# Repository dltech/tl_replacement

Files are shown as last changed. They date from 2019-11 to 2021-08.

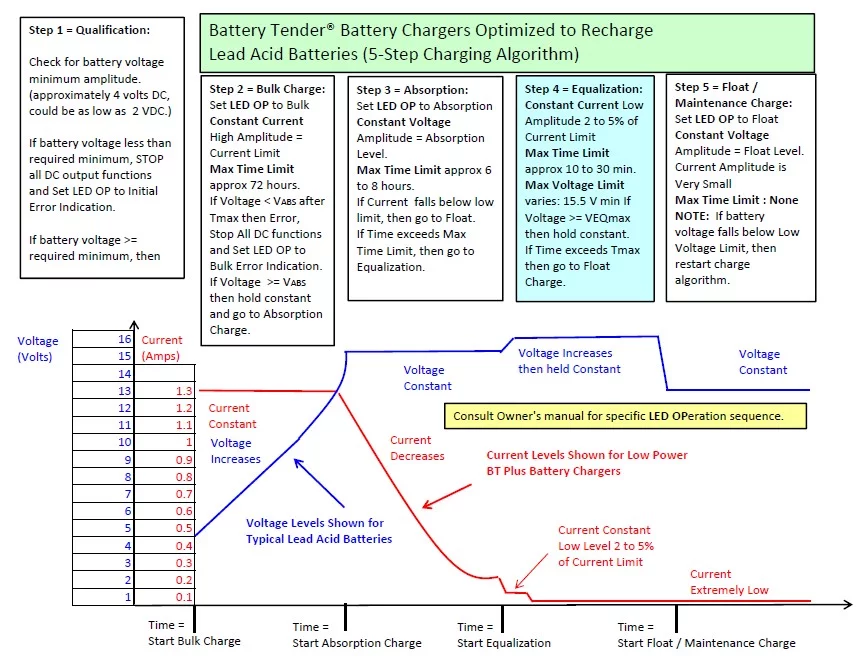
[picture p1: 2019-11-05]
sch_doc/datasheets/Lead_Acid_5_Step_Charging.webp

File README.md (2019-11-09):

A replacement for a driver in old ATX power suplies. May be conected direcly to
the coils of isolaton transformer. Powered by Vsb and controls only one channel
by current and volage. Includes submodule with display and simple menu. 
Functions:

Short circuit protection (checks every 0.1ms).

Current and voltage stabilization.

Mode for control charging 12V and 6V lead acid batteries.

Fan speed control.

It is based on libopencm3 libraries
# Instructions
 1. git clone https://github.com/libopencm3/libopencm3-template.git zarjadnik
 2. cd zarjadnik
 3. git submodule update --init # (Only needed once)
 4. make -C libopencm3 # (Only needed once)
 5. make -C zarjadnik

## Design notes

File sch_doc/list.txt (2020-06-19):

STM32F030F4P6	x1
78HC595		x2
AP1117-33	x1
0.1 мкФ		х8
10 нФ		х4
100 Ом		х3
200 Ом		х3
510 Ом		х1
1 кОм		х2
1.5 кОм		х1
4.7 кОм		х1
63 Ом 1210	х1
0.1 Ом 1210	х10
тактовая кнопка	х2
7 сегментник 	х1
потенциометр	х1
PLS		x5
винтовой разъем х2
BAW156		x1
BAV70		x1
BZX84-C5V1	x2
PESD1CAN	x1
47 мкГн 1210	х1
BCR158		x1
BCR108		x2

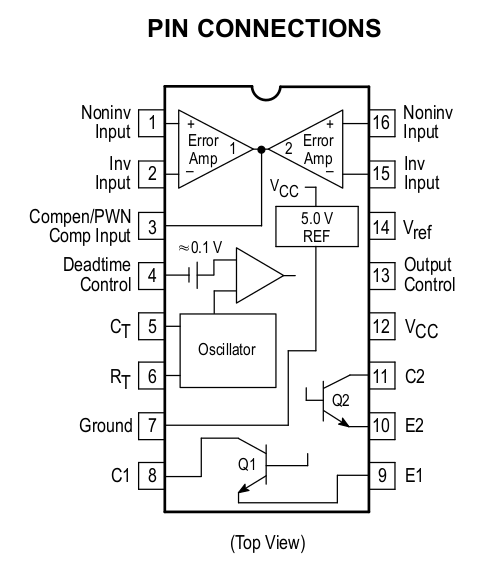
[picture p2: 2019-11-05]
sch_doc/datasheets/PWM diver/TL_PINOUT.png

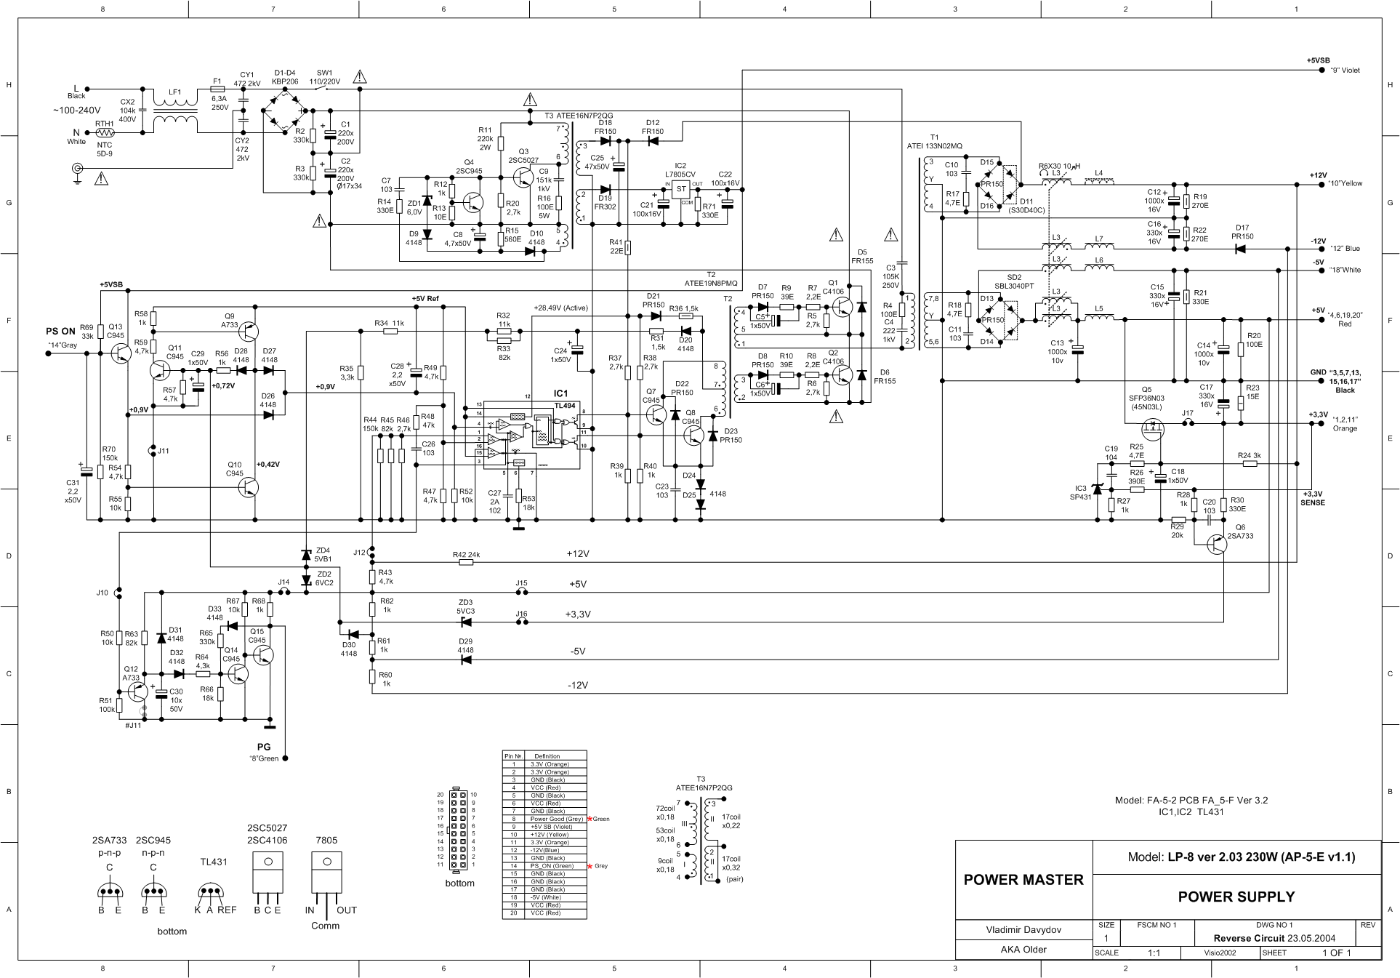
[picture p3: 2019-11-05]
sch_doc/datasheets/ATX/PowerMaster_LP-8-v.gif

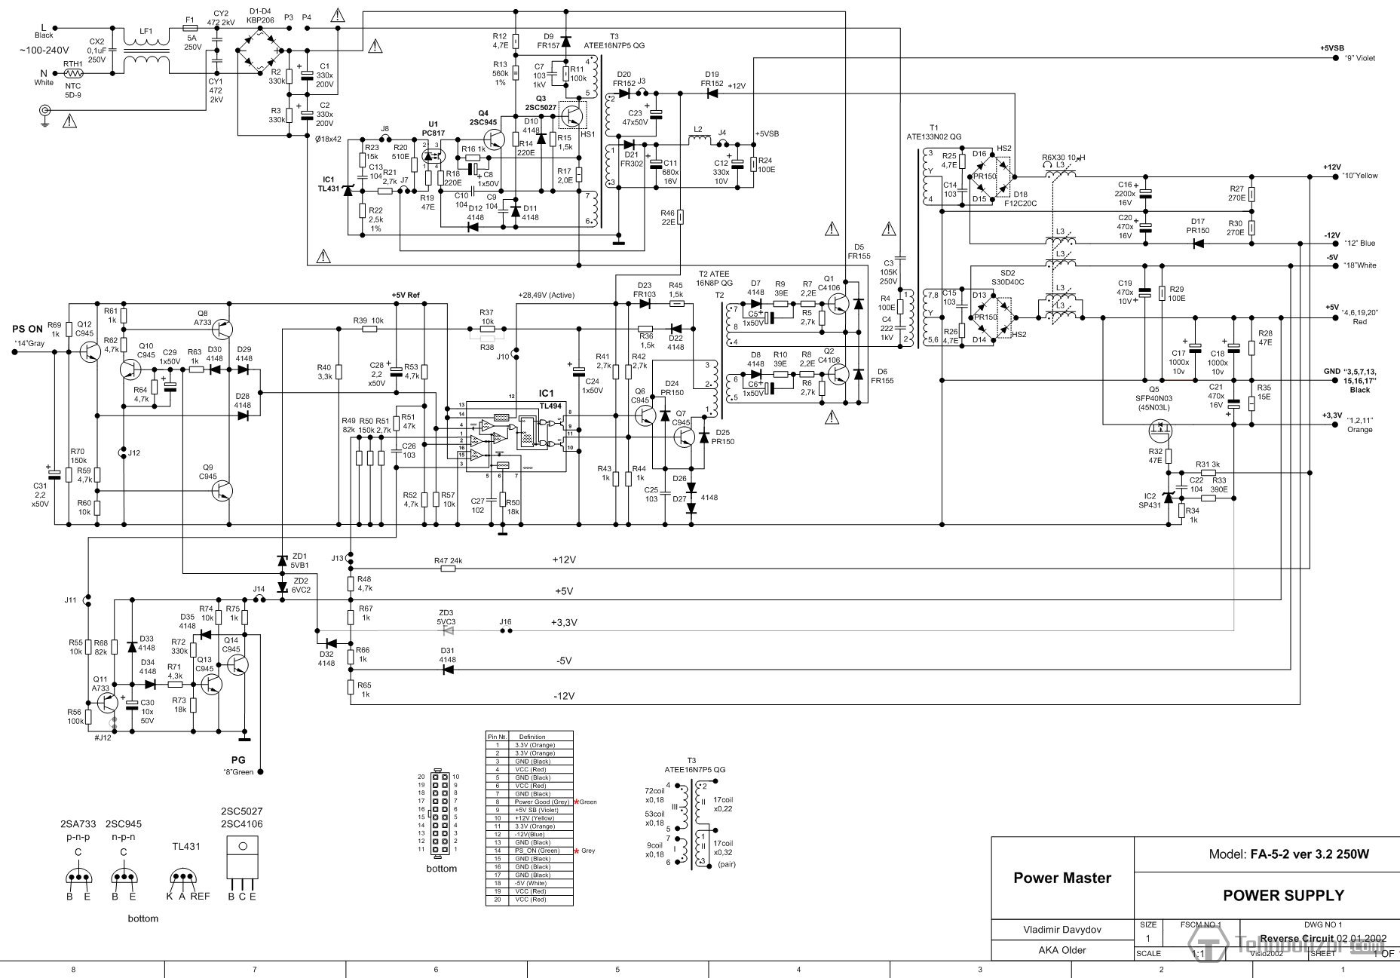
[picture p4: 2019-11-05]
sch_doc/datasheets/ATX/1368205779_shema-atx.jpg

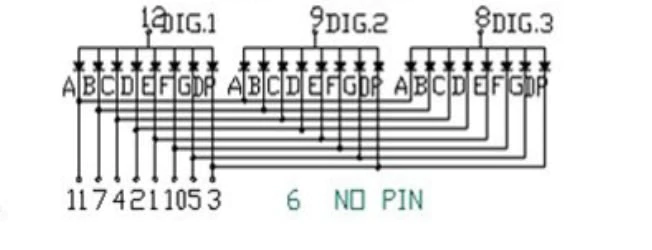
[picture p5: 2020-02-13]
sch_doc/datasheets/3 digits ali.webp

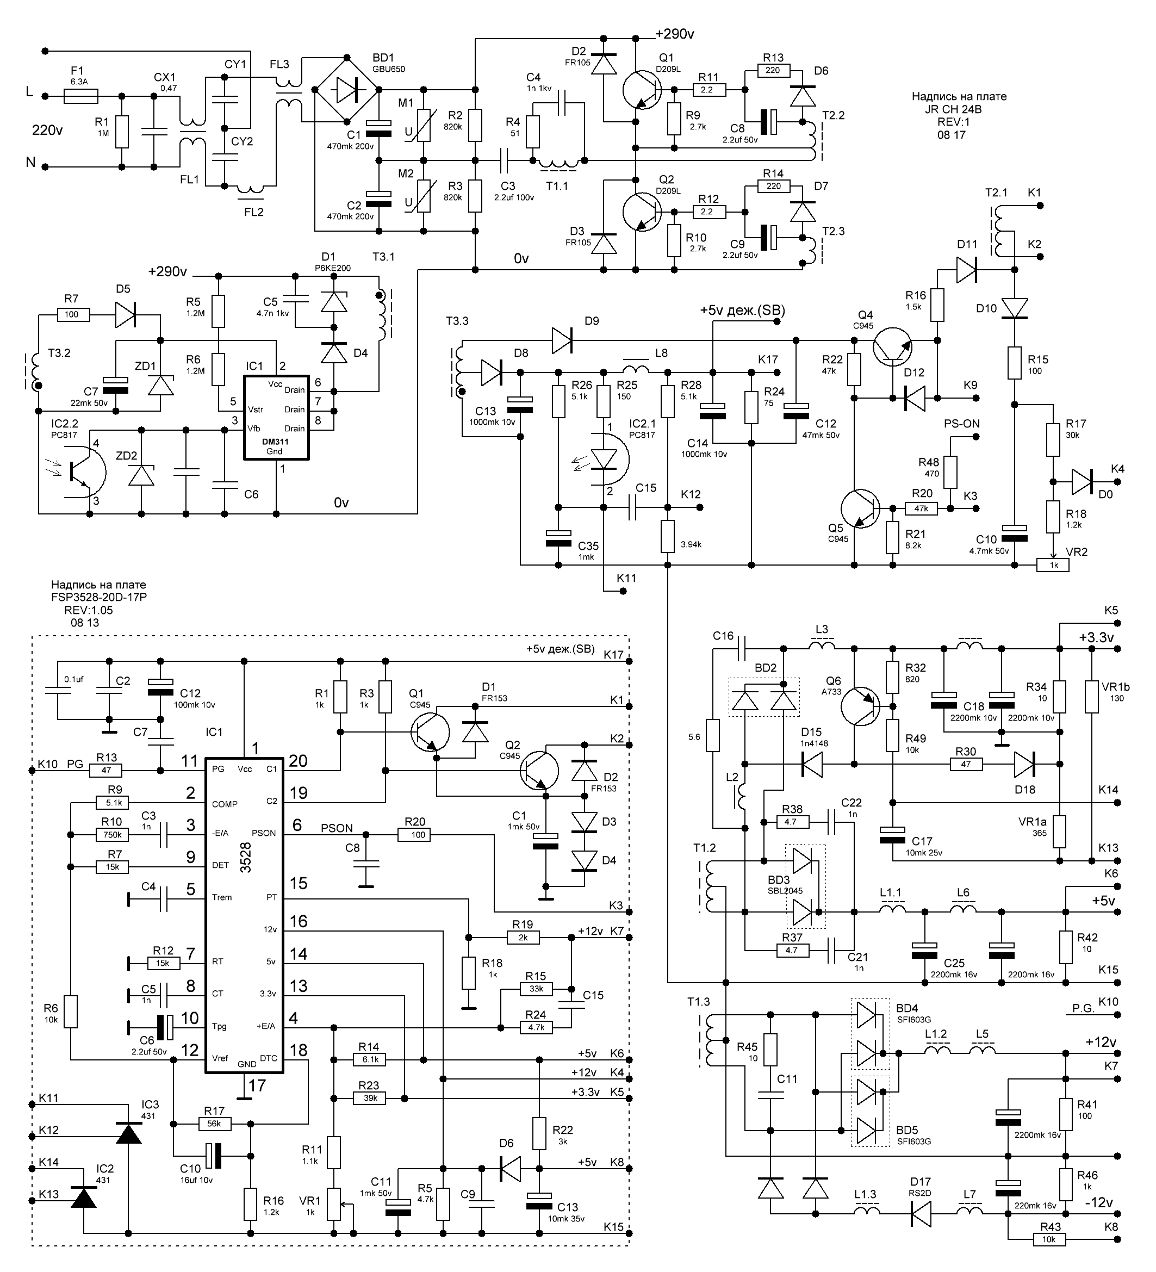
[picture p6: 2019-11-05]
sch_doc/datasheets/ATX/FSP_ATX-350PNR_DM311_FSP3528.gif

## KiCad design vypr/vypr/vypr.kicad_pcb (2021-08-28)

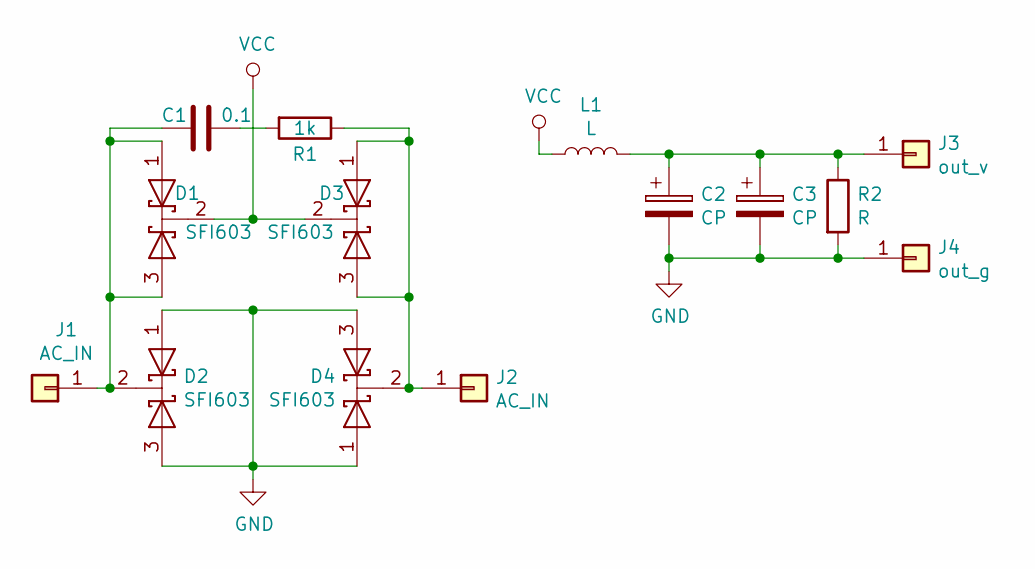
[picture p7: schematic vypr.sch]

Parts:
C1: 0.1; C_Disc_D6.0mm_W2.5mm_P5.00mm
C2, C3: CP; CP_Radial_D17.0mm_P7.50mm
D1, D2, D3, D4: SFI603; TO-220-3_Vertical
J1, J2: AC_IN; SolderWirePad_1x01_SMD_5x10mm
J3: out_v; SolderWirePad_1x01_SMD_5x10mm
J4: out_g; SolderWirePad_1x01_SMD_5x10mm
L1: L; L_Toroid_Vertical_L35.6mm_W17.8mm_P12.70mm_Pulse_E
R1: 1k; R_Axial_DIN0207_L6.3mm_D2.5mm_P7.62mm_Horizontal
R2: R; R_Axial_DIN0516_L15.5mm_D5.0mm_P7.62mm_Vertical

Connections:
GND: C2.2, C3.2, D2.1 (A), D2.3 (A), D4.1 (A), D4.3 (A), J4.1, R2.2
unnamed: C1.1, D1.1 (A), D1.3 (A), D2.2 (K), J1.1
unnamed: C1.2, R1.2
unnamed: C2.1, C3.1, J3.1, L1.2, R2.1
unnamed: D3.1 (A), D3.3 (A), D4.2 (K), J2.1, R1.1
VCC: D1.2 (K), D3.2 (K), L1.1

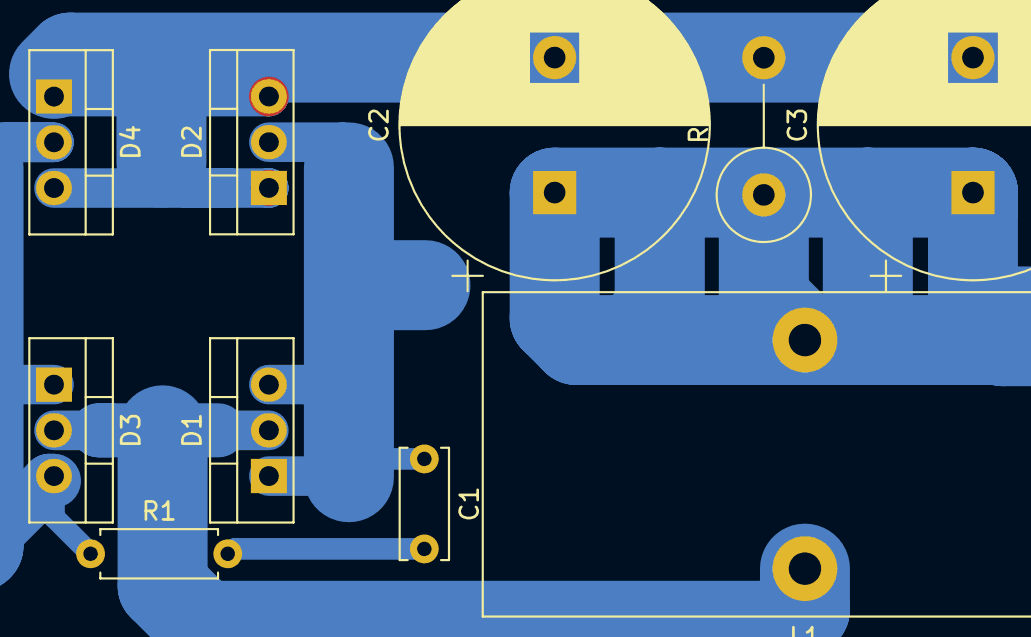
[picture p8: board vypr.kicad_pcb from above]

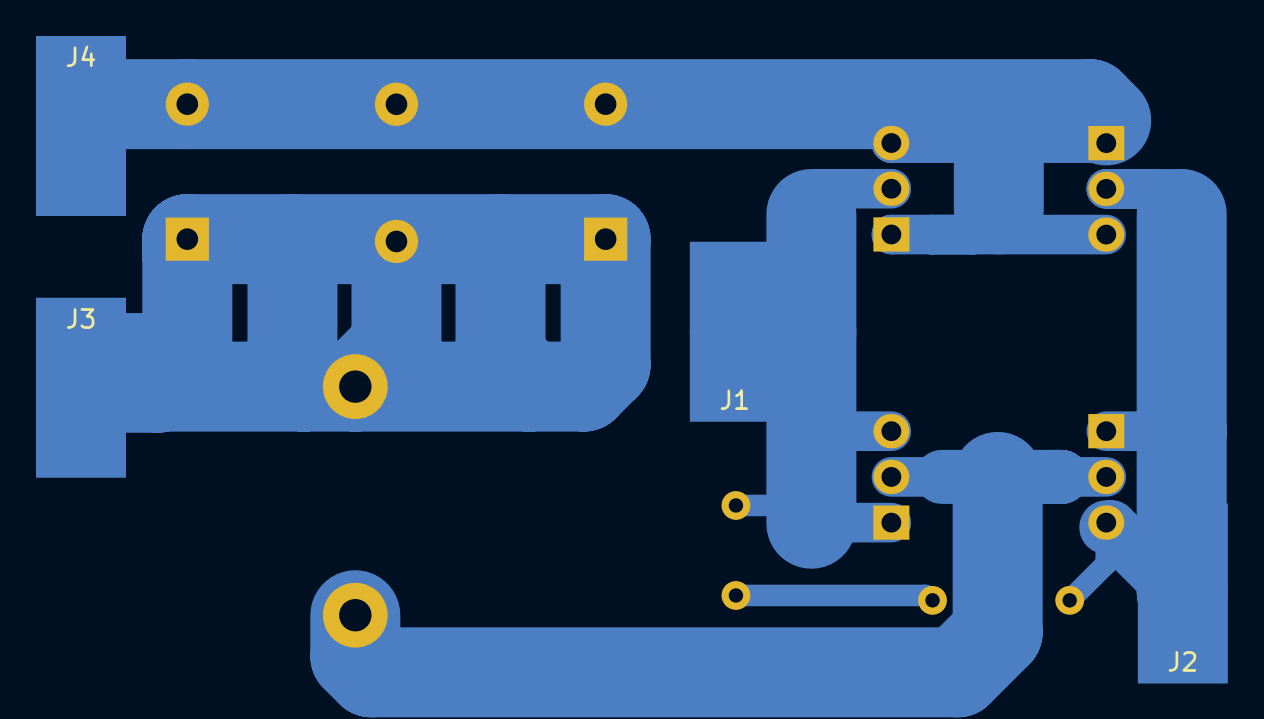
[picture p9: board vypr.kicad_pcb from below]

Board: 2 copper layers, 14 parts (4 on the bottom side), 6 nets.

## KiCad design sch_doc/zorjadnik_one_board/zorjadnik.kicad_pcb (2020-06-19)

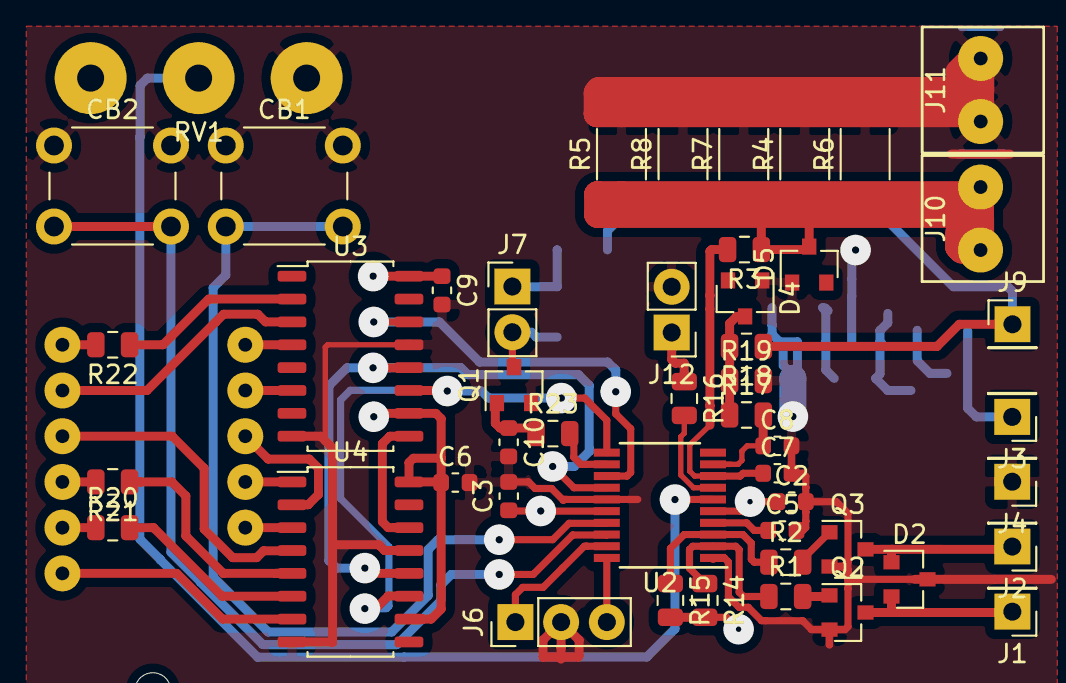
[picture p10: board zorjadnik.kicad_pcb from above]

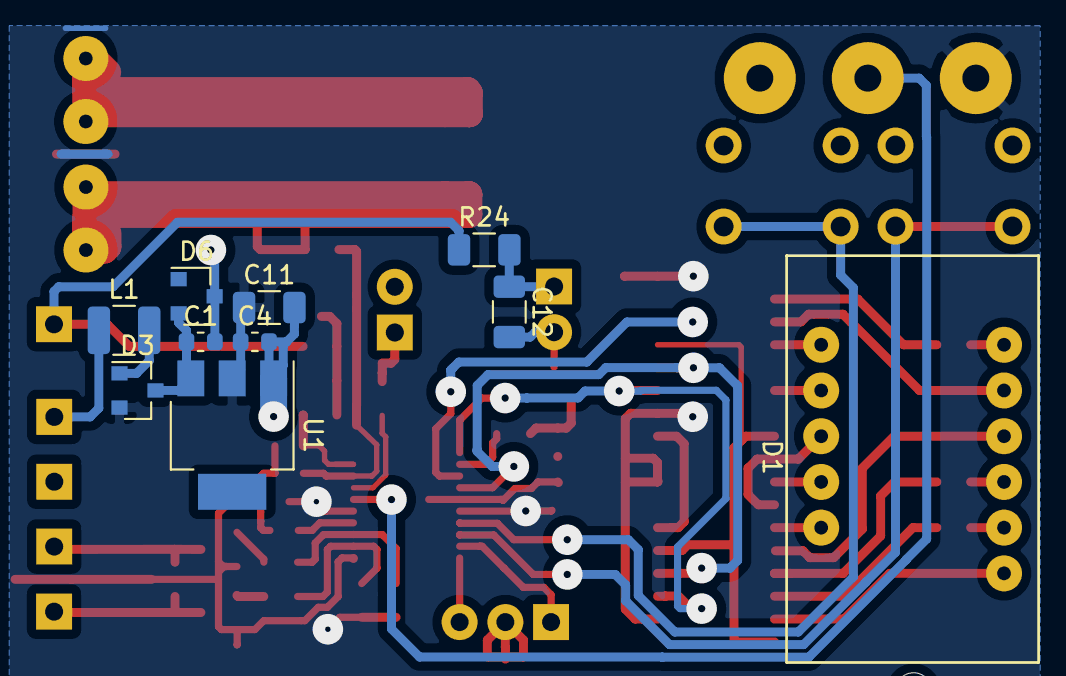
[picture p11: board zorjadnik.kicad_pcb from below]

Board: 2 copper layers, 58 parts (10 on the bottom side), 44 nets.

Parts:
C1, C2, C5, C10: 0.1; C_0603_1608Metric
C3, C4, C6, C9: 100nF; C_0603_1608Metric
C7, C8: 10n; C_0603_1608Metric
C11, C12: 10µF; C_1206_3216Metric
CB1: mode; SW_PUSH_6mm
CB2: select; SW_PUSH_6mm
D1: LED_3digit; FYT-3631_minimal
D2: BAT54; SOT-23
D3: BAV70; SOT-23
D4, D5: D_Zener; SOT-23
D6: PESD1CAN; D_SOT-23_NKA
J1: OUT1; PinHeader_1x01_P2.54mm_Vertical
J2: OUT2; PinHeader_1x01_P2.54mm_Vertical
J3: Vsb; PinHeader_1x01_P2.54mm_Vertical
J4: GND; PinHeader_1x01_P2.54mm_Vertical
J6: firmware; PinHeader_1x03_P2.54mm_Vertical
J7: cooling fan; PinHeader_1x02_P2.54mm_Vertical
J9: power supply Vout; PinHeader_1x01_P2.54mm_Vertical
J10: output GND; KF350x2
J11: power supply GND; KF350x2
J12: spare port; PinHeader_1x02_P2.54mm_Vertical
L1: 47µH; L_1210_3225Metric
Q1: BCR512; SOT-23
Q2, Q3: BCR108; SOT-23
R1, R2, R23: 100; R_0805_2012Metric
R3, R14, R15, R17: 1k; R_0805_2012Metric
R4, R5, R6, R7, R8: 0.1R; R_2010_5025Metric
R16: 1.5k; R_0805_2012Metric
R18: 4.7k; R_0805_2012Metric
R19: 510; R_0805_2012Metric
R20, R21, R22: 200; R_0805_2012Metric
R24: 63; R_1206_3216Metric
RV1: POT; СП3-4
U1: AP1117-33; SOT-223
U2: STM32F030F4Px; TSSOP-20_4.4x6.5mm_P0.65mm
U3, U4: 74HC595; SOP-16_4.55x10.3mm_P1.27mm

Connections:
+3V3: C2.1, C3.1, C4.1, C6.1, C9.1, C11.1, D3.2, R14.2, R15.2, RV1.3, U1.2, U2.5, U2.16, U3.10, U3.16, U4.10, U4.16
+28V: J3.1, L1.1
+VDC: J9.1, R18.1, R24.1
/SWCLK: J6.3, U2.20
/SWDIO: J6.1, U2.19
/Sheet5D41F71D/A: D1.11, U3.3
/Sheet5D41F71D/B: D1.7, U4.7
/Sheet5D41F71D/C: D1.4, U4.1
/Sheet5D41F71D/D: D1.2, U3.6
/Sheet5D41F71D/D1: R22.1, U3.2
/Sheet5D41F71D/D2: R21.1, U4.5
/Sheet5D41F71D/D3: R20.2, U4.6
/Sheet5D41F71D/DP: D1.3, U4.2
/Sheet5D41F71D/E: D1.1, U3.4
/Sheet5D41F71D/F: D1.10, U4.4
/Sheet5D41F71D/G: D1.5, U4.3
GND: C1.2, C2.2, C3.2, C4.2, C5.2, C6.2, C7.2, C8.2, C9.2, C10.2, C11.2, CB1.1, CB2.1, D2.3, D4.1, D5.1, D6.2, J4.1, J6.2, J11.1, J11.2, J12.2, Q1.2, Q2.2, Q3.2, R4.2, R5.2, R6.2, R7.2, R8.2, R19.2, RV1.1, U1.1, U2.1, U2.15, U3.8, U3.13, U4.8, U4.13
MOSI: U2.13, U3.14
unnamed: C1.1, D3.3, D6.1, U1.3
unnamed: C5.1, U2.4
unnamed: C7.1, R3.2, U2.8
unnamed: C8.1, R17.2, U2.9
unnamed: C10.1, Q1.1, R23.1
unnamed: C12.1, J7.1, R24.2
unnamed: C12.2, J7.2, Q1.3
unnamed: D1.8, R20.1
unnamed: D1.9, R21.2
unnamed: D1.12, R22.2
unnamed: D2.1, J2.1, Q3.3
unnamed: D2.2, J1.1, Q2.3
unnamed: D3.1, L1.2
unnamed: D4.3, R17.1, R18.2, R19.1
unnamed: D5.3, J10.1, J10.2, R3.1, R4.1, R5.1, R6.1, R7.1, R8.1
unnamed: J12.1, R16.1
unnamed: R1.1, R14.1, U2.2
unnamed: R2.1, R15.1, U2.3
unnamed: R16.2, U2.7
unnamed: R23.2, U2.12
unnamed: U3.9, U4.14
SCK: U2.11, U3.11, U4.11
ST_CP: U2.14, U3.12, U4.12
mode_but: CB1.2, U2.17
pot: RV1.2, U2.6
sel_but: CB2.2, U2.18

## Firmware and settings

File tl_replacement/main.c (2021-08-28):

#include <stdint.h>
#include <stdio.h>
#include <stdlib.h>
#include "board.h"
#include "tl.h"
#include "measure.h"
#include "settings.h"
#include "menu.h"
#include "display.h"




int main(void)
{
    // RCC_AHBENR |= TLOUT_RCC_EN;
    // gpio_set(TLOUT_PORT, TL1OUT_PIN | TL2OUT_PIN);
    // gpio_mode_setup(TLOUT_PORT, GPIO_MODE_OUTPUT, GPIO_PUPD_NONE, TL1OUT_PIN | TL2OUT_PIN);
    // gpio_set_output_options(TLOUT_PORT, GPIO_OTYPE_PP, GPIO_OSPEED_100MHZ, TL1OUT_PIN | TL2OUT_PIN);

    clkInit();
    displayInit();
    fanInit();
    setInit();
    menuInit();
    tlInit();

    while(1);
}

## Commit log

2019-11-05 протестированный вариант зарядника с защитой по питанию драйвера
    [file5D41F71D.sch, zorjadnik.kicad_pcb, zorjadnik.sch]
2019-11-09 навел красивостей в схеме
    [file5D41F71D.sch, zorjadnik.kicad_pcb, zorjadnik.sch]
2019-11-09 навел порядок в datasheets
    [zorjadnik.kicad_pcb]
2019-11-26 что то подкрутил
    [zorjadnik.kicad_pcb, zorjadnik.sch]
2020-01-13 поаккуратней схема
    [zorjadnik.kicad_pcb]
2020-01-23 немного комментариев в коде, вариант с одной платой (одна 5х3 вместо двух 3х3)
    [file5D41F71D.sch, zorjadnik.kicad_pcb, zorjadnik.sch]
2020-01-29 собрал
    [zorjadnik.kicad_pcb]
2020-02-13 полирнул меню, теперь есть функция выкючения
    [file5D41F71D.sch, zorjadnik.kicad_pcb]
2020-02-16 список компонентов
    [file5D41F71D.sch, zorjadnik.kicad_pcb, zorjadnik.sch]
2020-02-21 еще покрутил меню
2020-02-23 убрал сохранение настроек, не умею в такое
    [file5D41F71D.sch, zorjadnik.kicad_pcb, zorjadnik.sch]
2020-02-27 добавил сохрааниение настроек, подправил переменник, не проверял
    [zorjadnik.sch]
2020-03-07 раньше повисал теперь не висит
2020-04-06 переменник постабильней
2020-06-19 наладил, как сделаю трансформатор, так будет релиз
    [zorjadnik.kicad_pcb, zorjadnik.sch]
2021-08-28 new sch
    [FSP350 (1-я копия).sch, FSP350.kicad_pcb, FSP350.sch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]
